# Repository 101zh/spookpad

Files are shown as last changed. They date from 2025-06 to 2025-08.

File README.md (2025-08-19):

# Spookpad

A 3x3 macropad made with the help of [Hack Club](https://hackclub.com/)'s [Hackpad](https://hackpad.hackclub.com) program.\
There are 8 keys that are backlit with LEDs, a rotary encoder, an OLED screen, and a XIAO RP2040 as the microcontroller.

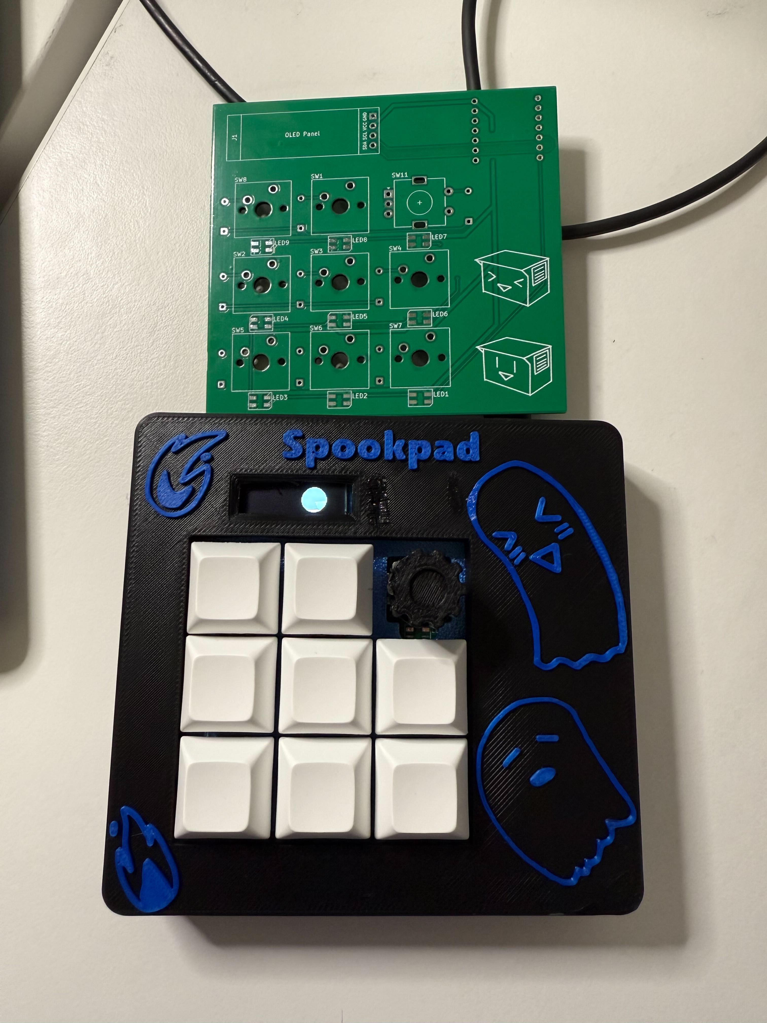
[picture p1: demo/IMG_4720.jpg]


https://github.com/user-attachments/assets/52a98100-4cb5-45ce-95d2-a7054d29ba24

## CAD

The case fits together using four M3 bolts and four M3 heatset inserts.\
The case is made of three separate printed pieces.\
The PCB just floats inside the 3D printed case. I would suggest that some insulation or some other material is placed inside, so that the PCB can be properly supported, instead of being supported by the sautered joints.

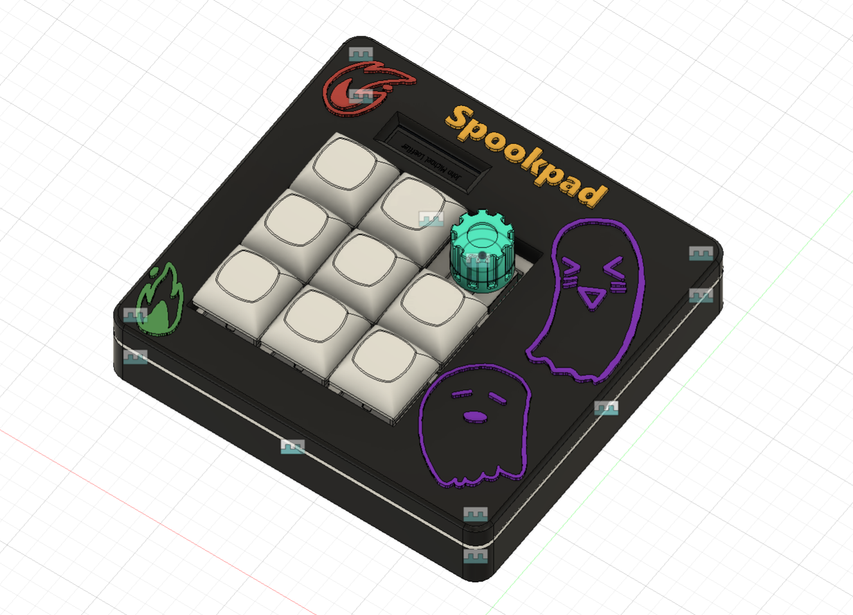
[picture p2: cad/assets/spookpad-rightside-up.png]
An image of the spookpad rightside up

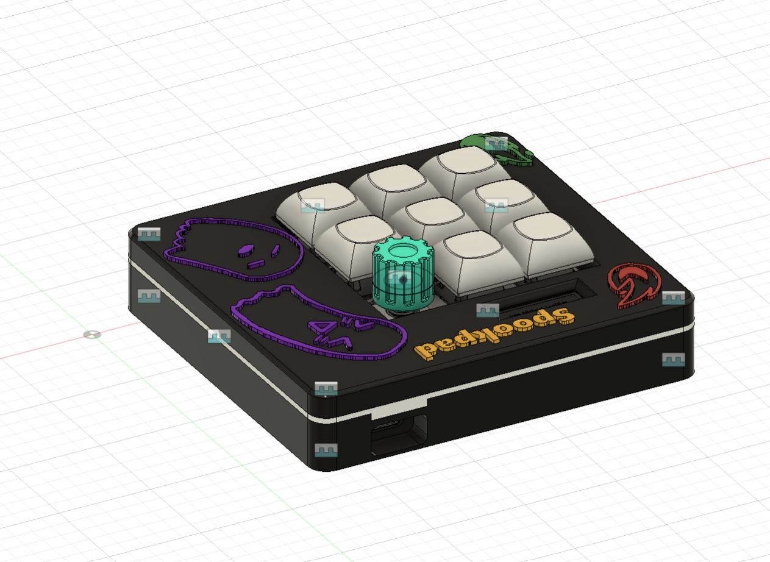
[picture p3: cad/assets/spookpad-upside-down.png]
An image of the spookpad upside down


## PCB

The PCB was created in KiCad. The silkscreen images were imported using KiCad's image converter.

### Schematic

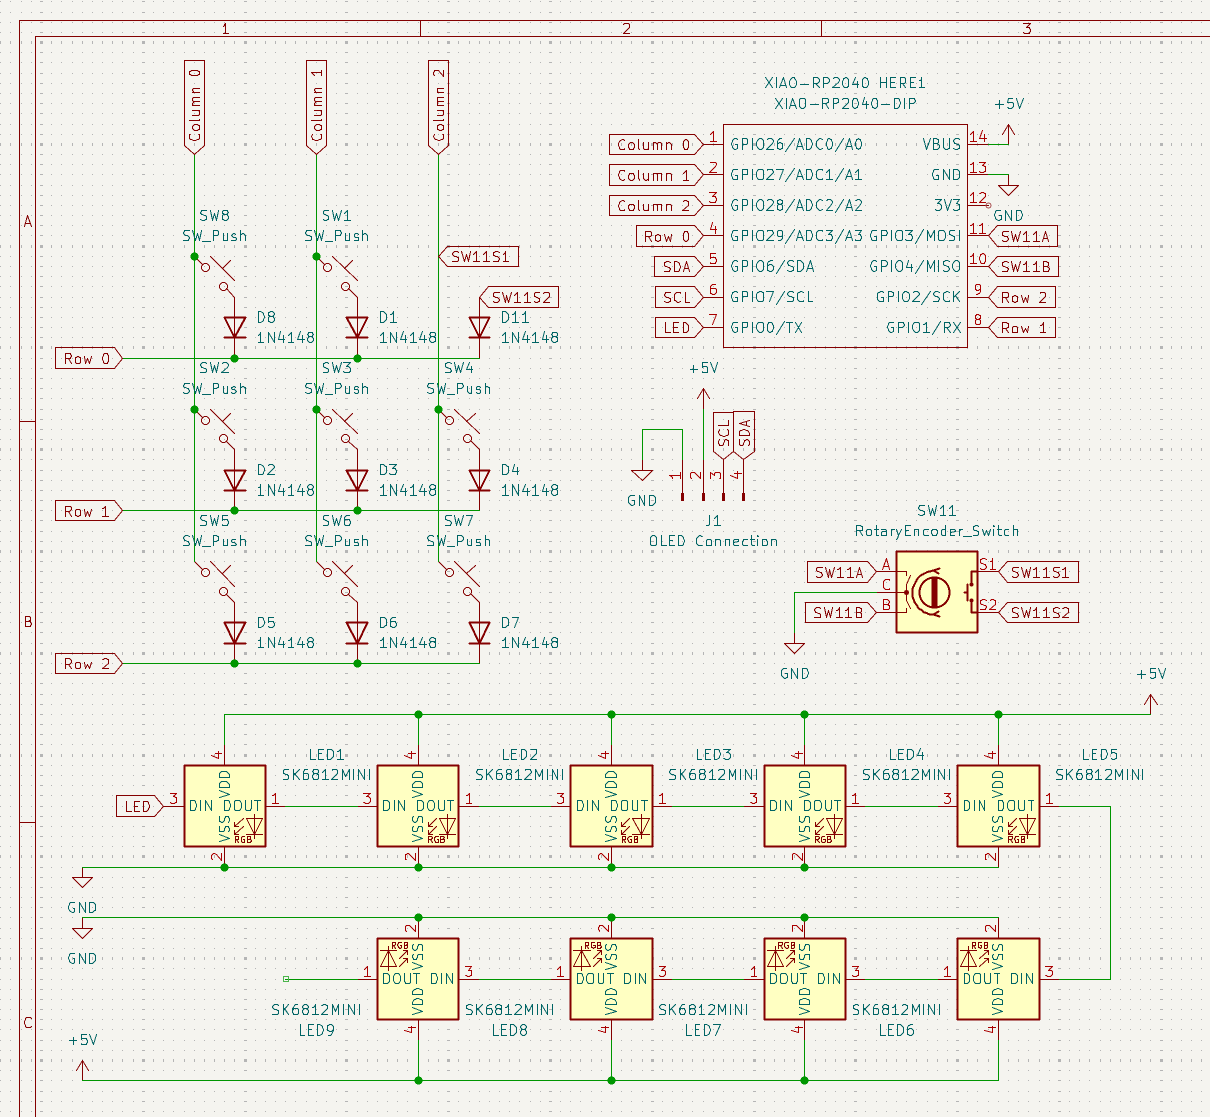
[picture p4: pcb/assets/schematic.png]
An image of the schematic, containing a wired key matrix, a micro controller, LEDs, and a rotary encoder


#### PCB With Zones

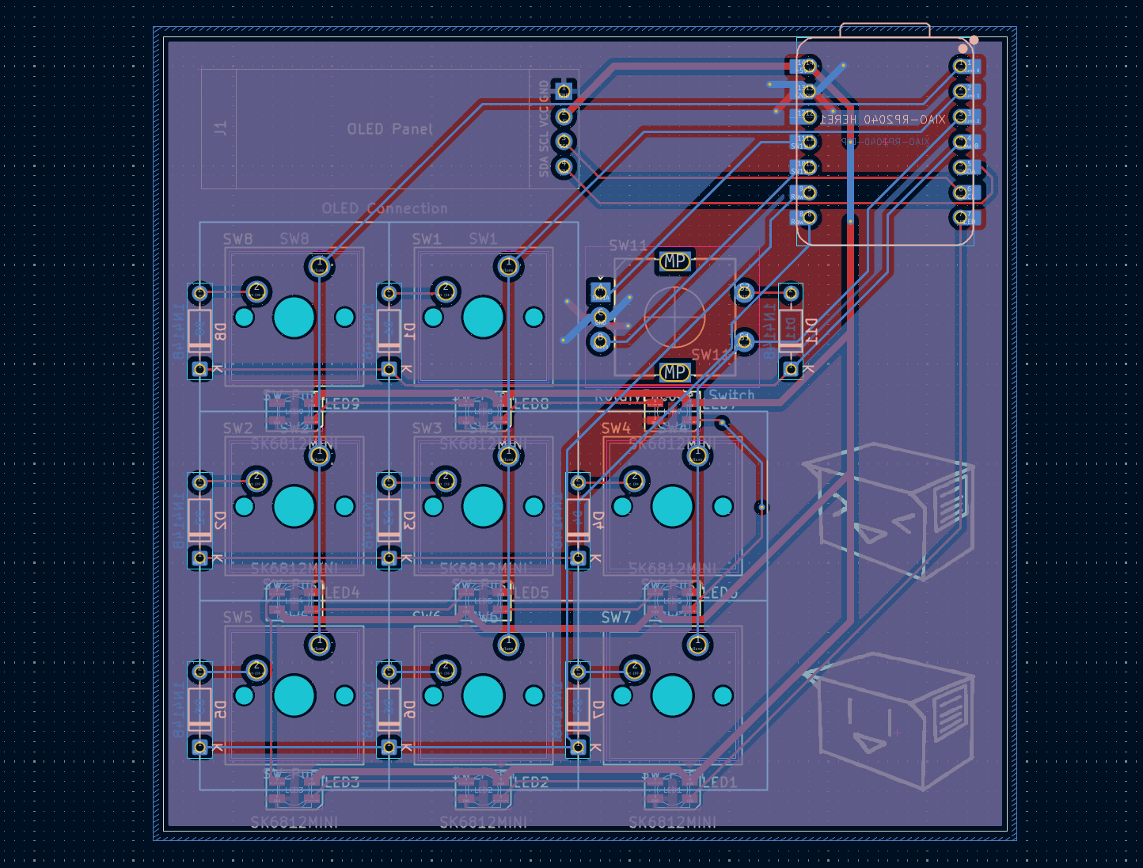
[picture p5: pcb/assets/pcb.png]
An image of the PCB with zones toggled as visible


#### PCB Without Zones

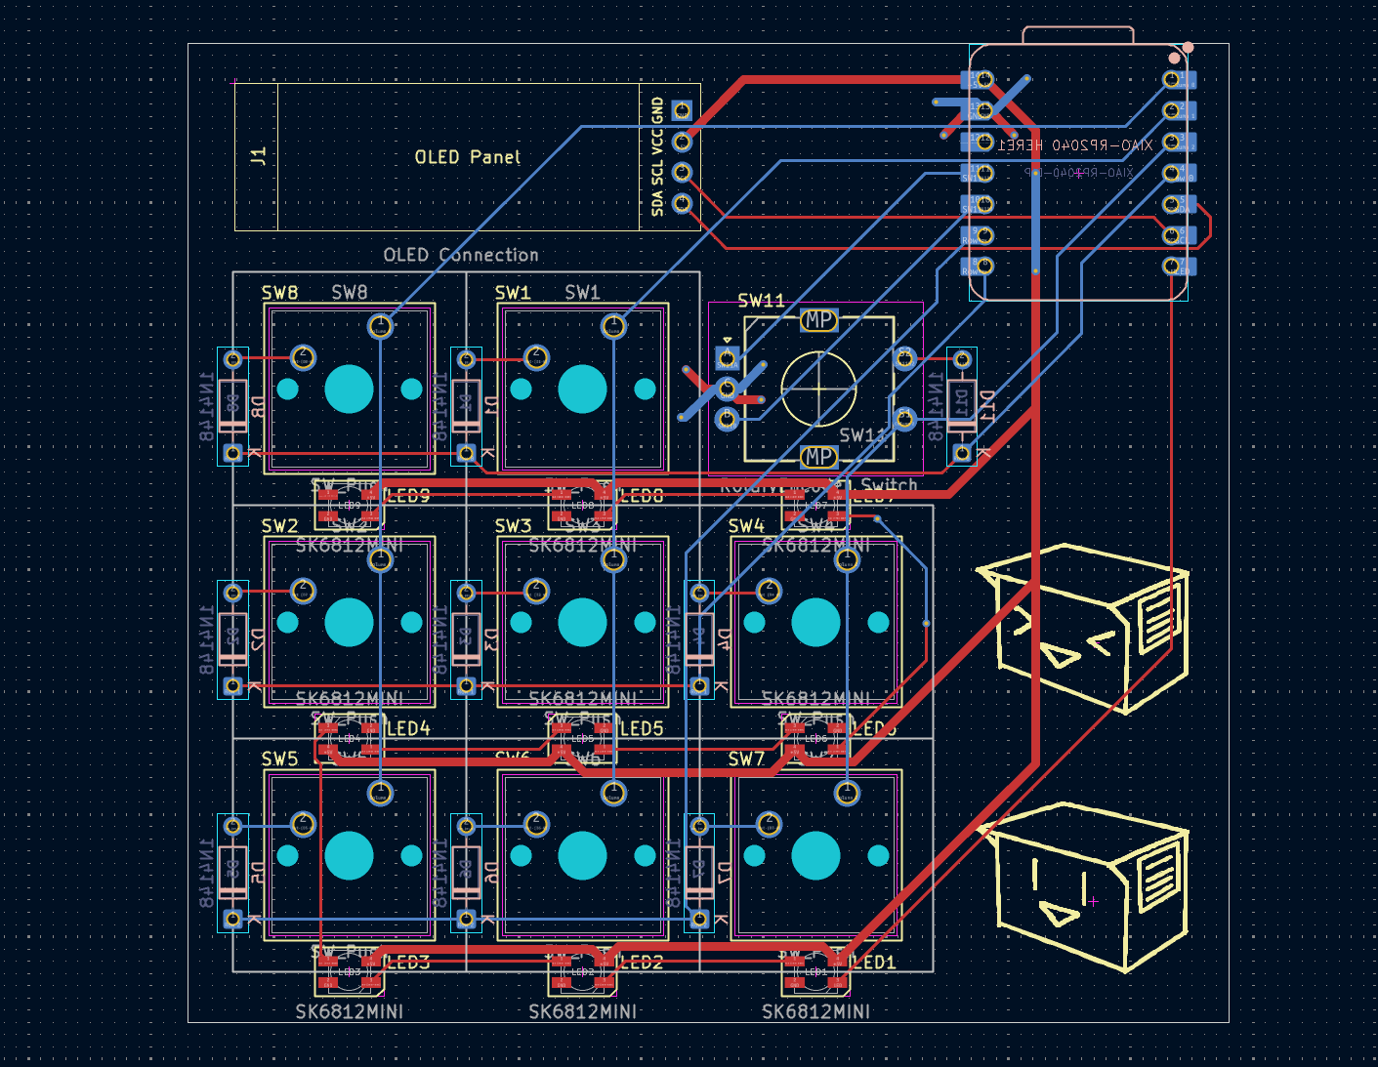
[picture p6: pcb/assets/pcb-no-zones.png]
An image of the PCB with zones toggled as not visible


## Firmware

This macropad uses [QMK](https://docs.qmk.fm/) for firmware.

- Rotary encoder knob adjusts the volume.
- By default, each key is bound to type out a number. The keys can type out the numbers 1 through 9. (There aren't enough keys to type out the number 0)
- This macropad is compatible with [VIA](https://caniusevia.com/), so that it can actually macro.
- The OLED screen should play the animation below at all times\
a .gif file of the animation, which shows a ball that flies back and forth
  - Still playing with the idea of displaying useful information.

## Bill of Materials (BOM)

Physical materials needed to make this macropad:

- 8x Cherry MX Switches
- 8x DSA Keycaps
- 1x EC11 Rotary Encoder
- 9x Through-hole 1N4148 Diodes
- 9x SK6812 MINI LEDs
- 4x M3x16mm Screws
- 4x M3x5mx4mm Heatset Inserts
- 1x 0.91" OLED Display
- 1x Seeed Studio XIAO RP2040
- 1x 3D printed knob for the rotary encoder
- 1x 3D printed case (3 separate pieces)

## Copyright

Copyright (C) 2025 101zh

This Source Code Form is subject to the terms of the Mozilla Public License, v. 2.0. If a copy of the MPL was not distributed with this file, You can obtain one at <https://mozilla.org/MPL/2.0/>.

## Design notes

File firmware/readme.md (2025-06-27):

# 101zh/spookinator

101zh/spookinator

*A short description of the keyboard/project*

* Keyboard Maintainer: [101zh](https://github.com/101zh)
* Hardware Supported: *The PCBs, controllers supported*
* Hardware Availability: *Links to where you can find this hardware*

Make example for this keyboard (after setting up your build environment):

    make 101zh/spookinator:default

Flashing example for this keyboard:

    make 101zh/spookinator:default:flash

See the [build environment setup](https://docs.qmk.fm/#/getting_started_build_tools) and the [make instructions](https://docs.qmk.fm/#/getting_started_make_guide) for more information. Brand new to QMK? Start with our [Complete Newbs Guide](https://docs.qmk.fm/#/newbs).

## Bootloader

Enter the bootloader in 3 ways:

* **Bootmagic reset**: Hold down the key at (0,0) in the matrix (usually the top left key or Escape) and plug in the keyboard
* **Physical reset button**: Briefly press the button on the back of the PCB - some may have pads you must short instead
* **Keycode in layout**: Press the key mapped to `QK_BOOT` if it is available

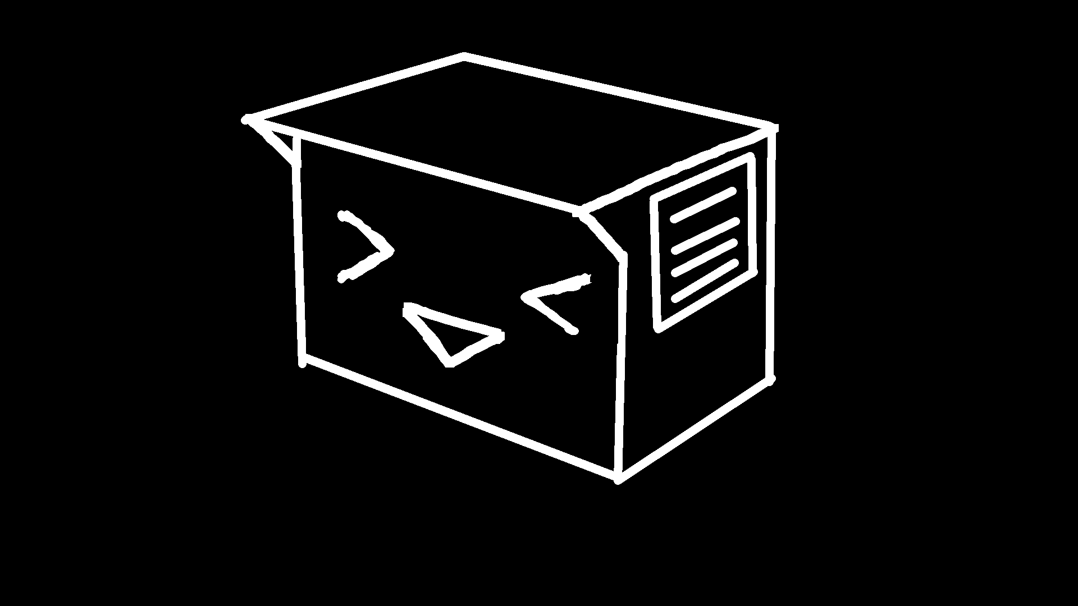
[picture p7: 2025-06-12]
pcb/assets/silkscreen/tv2.png

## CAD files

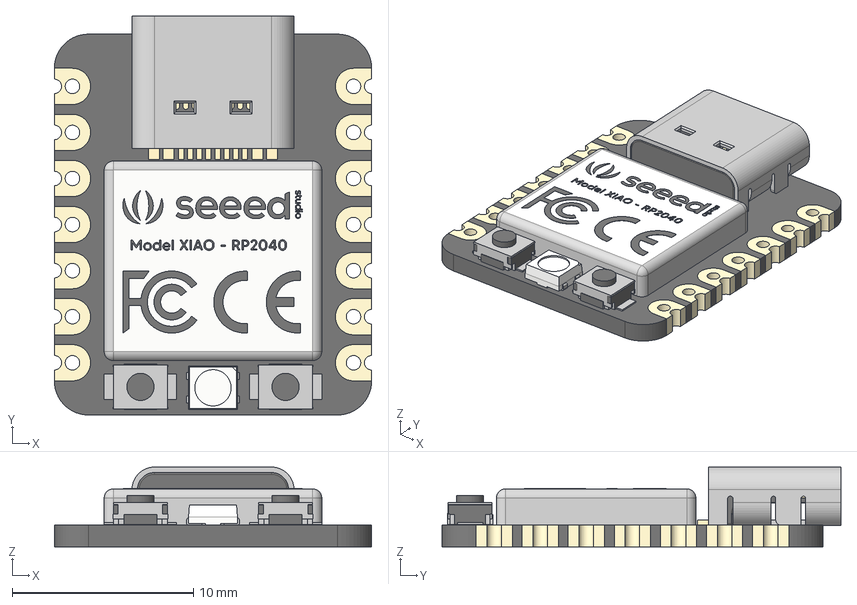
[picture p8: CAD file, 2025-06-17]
pcb/assets/3D_Models/Seeed Studio XIAO RP2040 v26.step
17.5 x 22.0 x 4.40 mm
Seeed Studio XIAO RP2040 v1 x 36
type-c v2 x 24
main x 16
smd_button v3
DIN
VDD
VSS
DOUT
smd_button v3(Mirror)

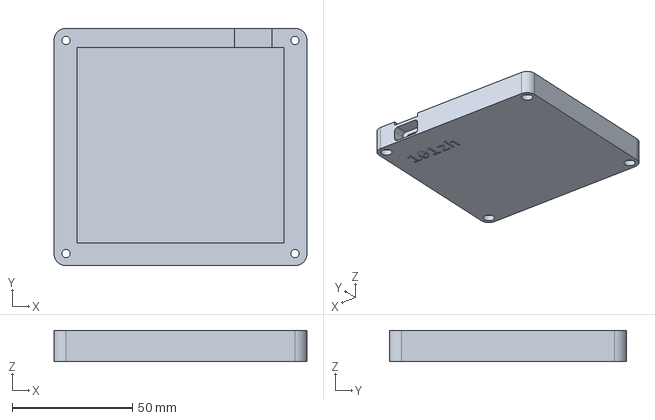
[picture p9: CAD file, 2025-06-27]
production/BottomCase.step
105.0 x 98.5 x 13.0 mm

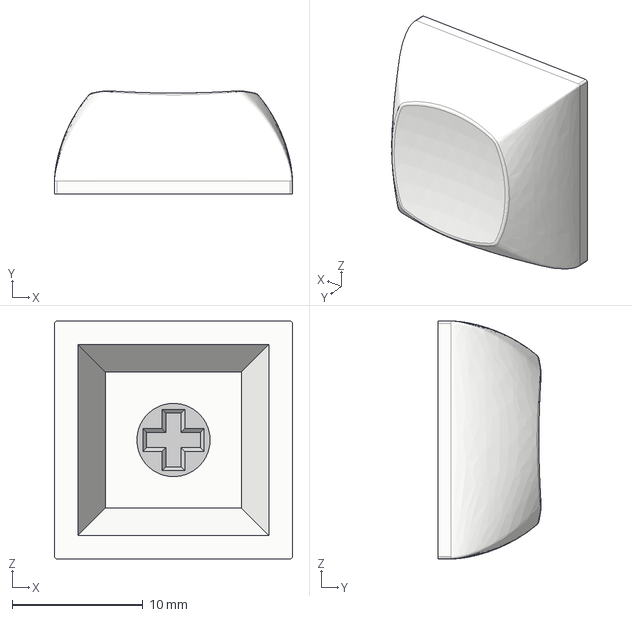
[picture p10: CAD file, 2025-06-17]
pcb/assets/3D_Models/DSA 1u v2.step
18.2 x 7.91 x 18.2 mm
DSA 1u v2
MX Mount v1

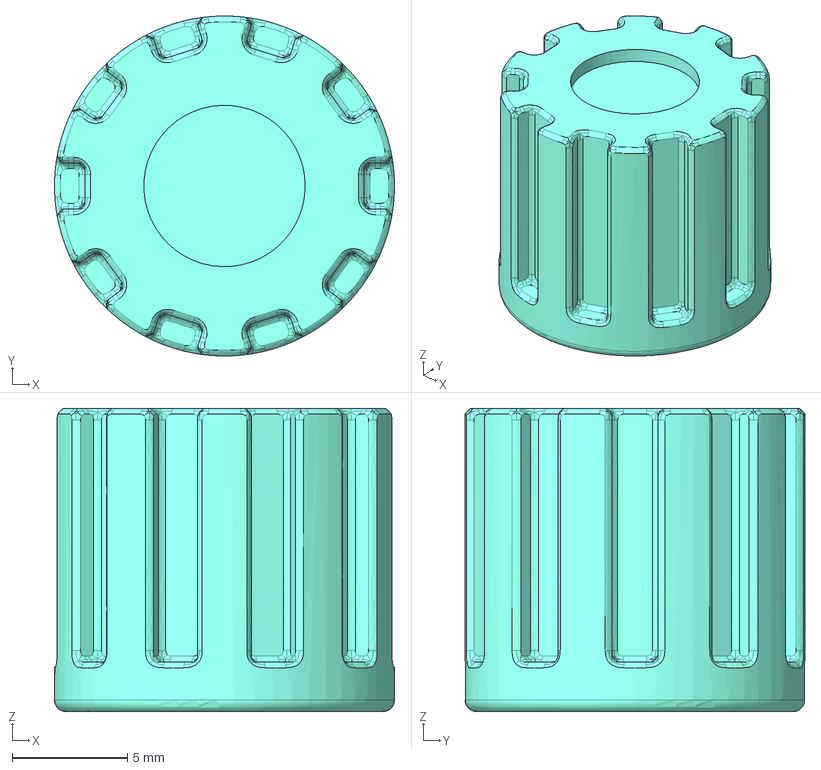
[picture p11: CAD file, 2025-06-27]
production/Knob.step
14.8 x 14.7 x 13.2 mm

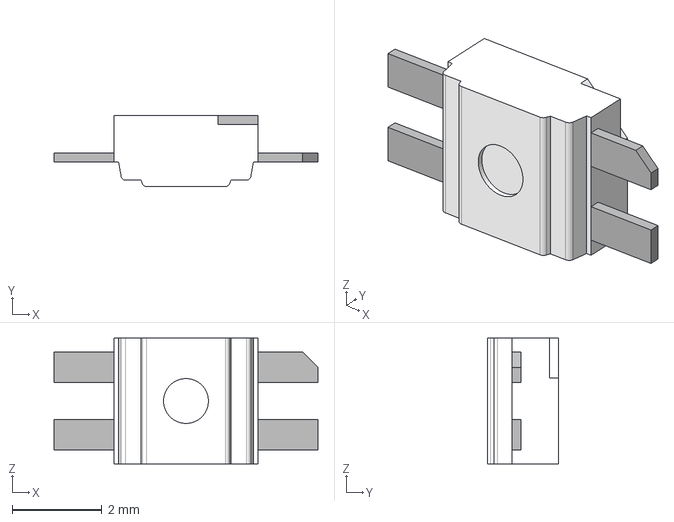
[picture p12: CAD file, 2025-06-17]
pcb/assets/3D_Models/SK6812MINI-E v1.step
5.88 x 1.58 x 2.80 mm

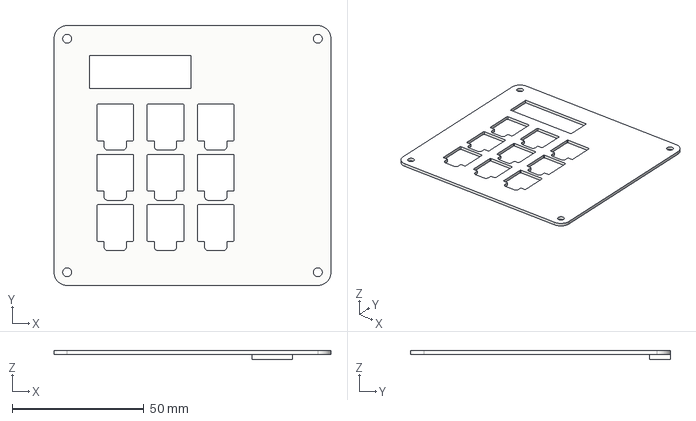
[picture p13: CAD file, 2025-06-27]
production/MiddleCase.step
105.0 x 98.5 x 3.45 mm

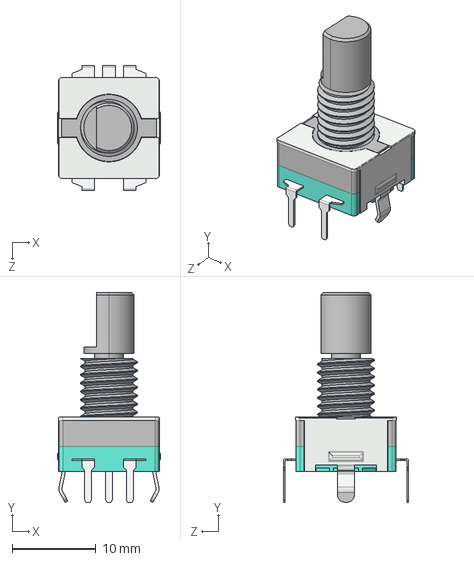
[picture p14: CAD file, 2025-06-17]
pcb/assets/3D_Models/EC11RotaryEncoder.STEP
12.3 x 25.1 x 15.0 mm

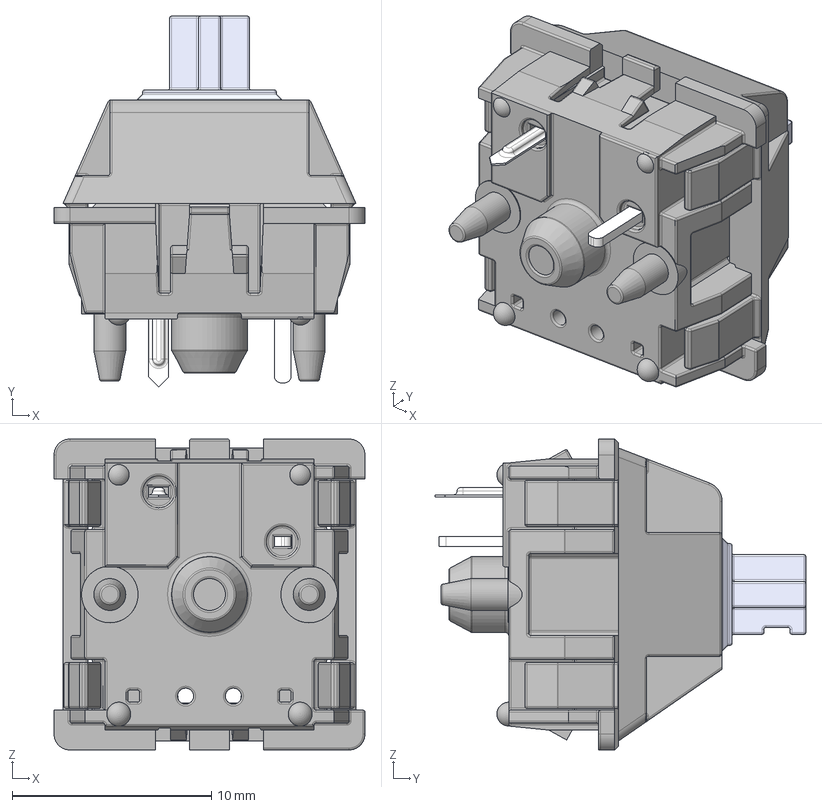
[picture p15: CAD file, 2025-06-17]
pcb/assets/3D_Models/Cherry MX Switch Base v2.step
15.6 x 18.6 x 15.6 mm
���___Ĭ��__��_ x 2
MX�� ���� �ײ� �̡�2 __Ĭ��_��2____��_
MX �� ������_��_ __��1
MX �� ���娢��_���顧_ _

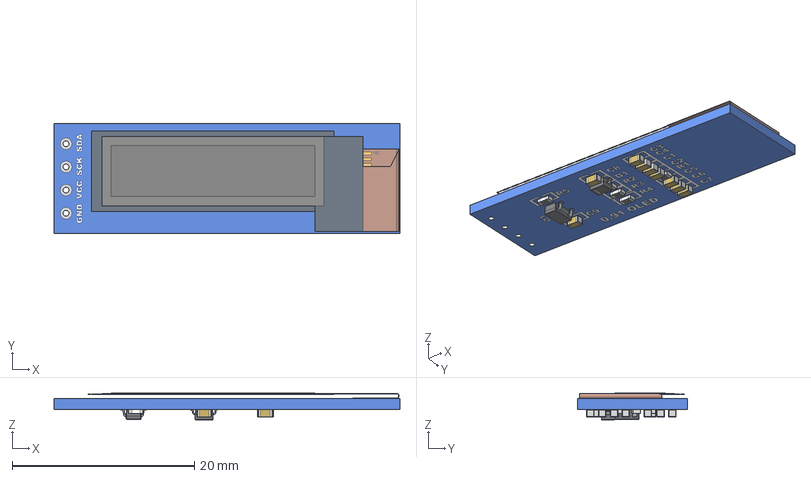
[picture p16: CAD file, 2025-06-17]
pcb/assets/3D_Models/0.91in OLED Module - Without Glass v1.step
37.9 x 12.1 x 2.93 mm
0603 Capacitor x 9
SOT23-3
Diode (SOD-323)
0.91in OLED - Folded Flush - Without Glass x 2
0603 Resistor x 5
0.91in oled Module - Board

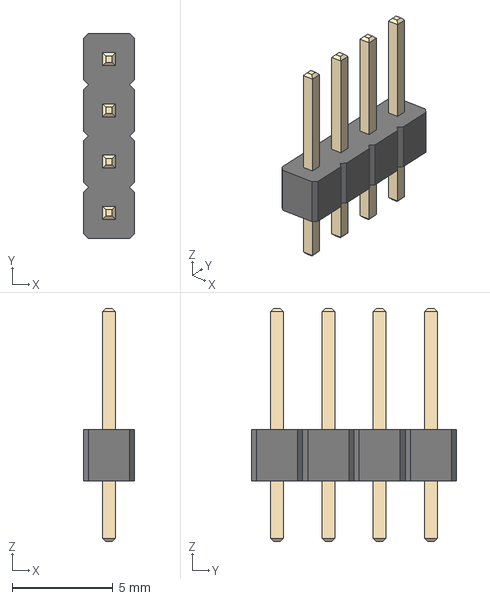
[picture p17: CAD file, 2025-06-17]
pcb/assets/3D_Models/PinHeader_1x04_P2.54mm_Vertical.step
2.54 x 10.2 x 11.5 mm

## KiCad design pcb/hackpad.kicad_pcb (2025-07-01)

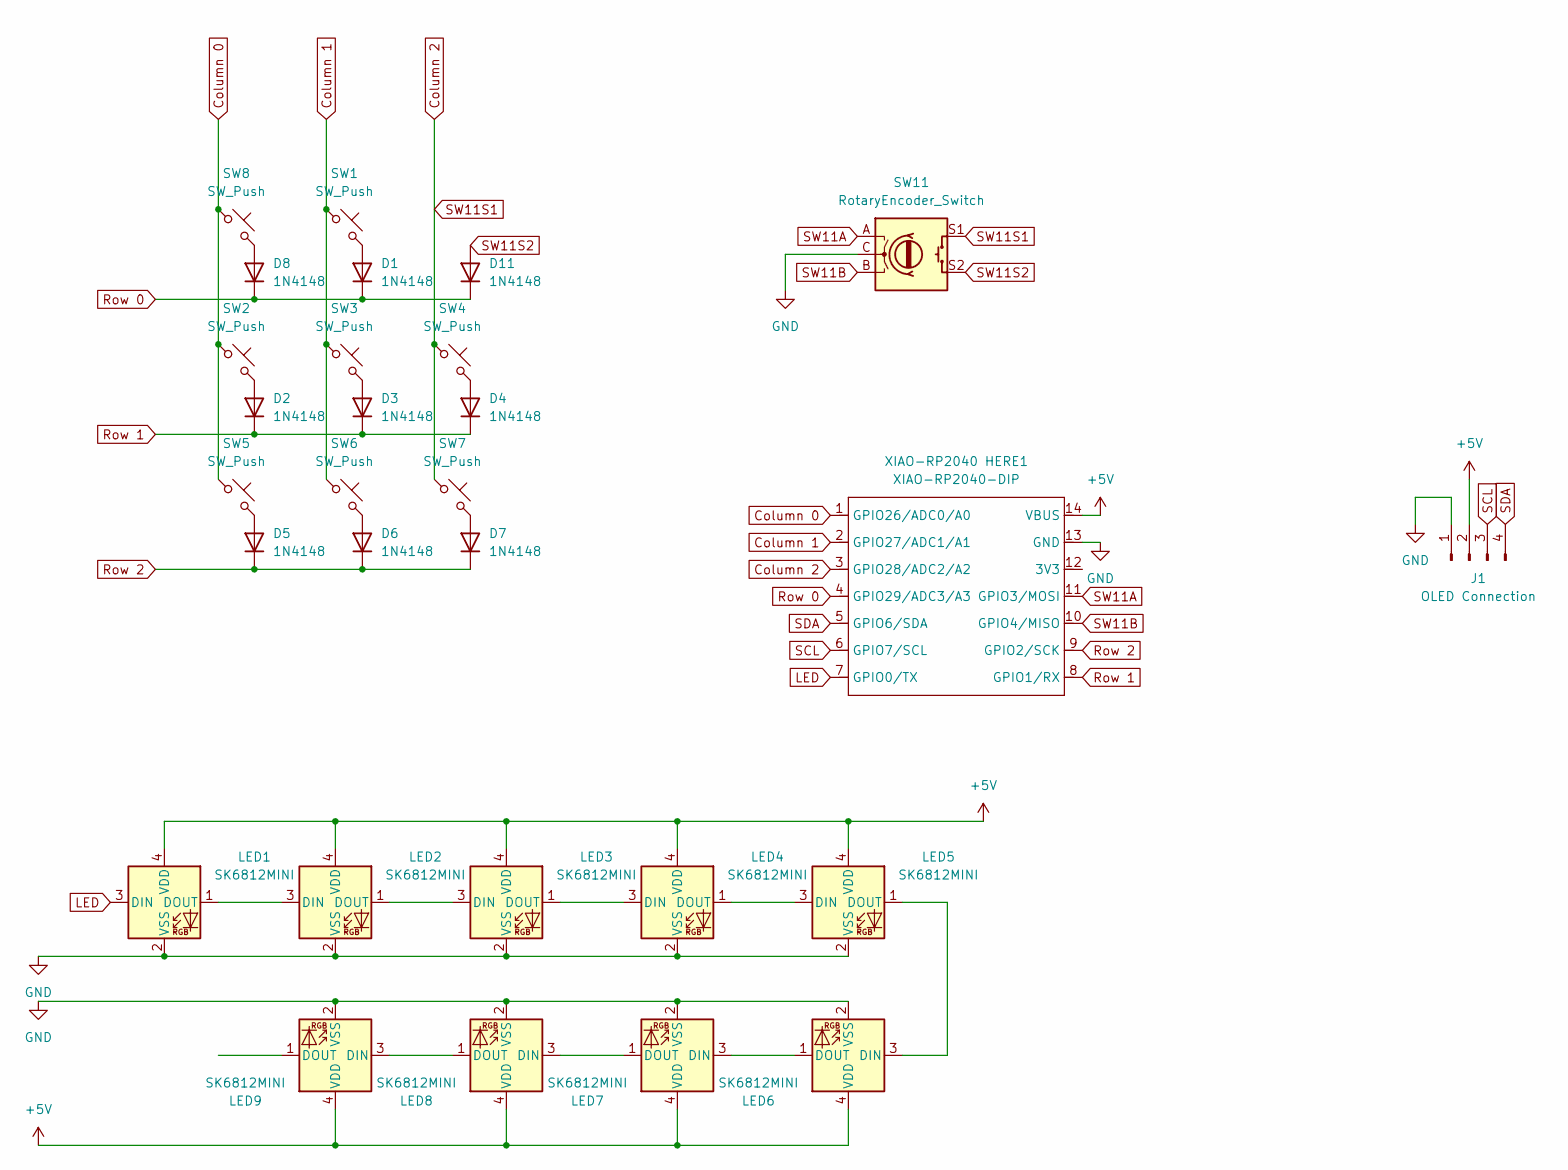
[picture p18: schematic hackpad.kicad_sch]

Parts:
D1, D2, D3, D4, D5, D6, D7, D8, D11: 1N4148; D_DO-35_SOD27_P7.62mm_Horizontal
J1: OLED Connection; 0.91-OLED-4pin
LED1, LED2, LED3, LED4, LED5, LED6, LED7, LED8, LED9: SK6812MINI; LED_SK6812MINI
SW1, SW2, SW3, SW4, SW5, SW6, SW7, SW8: SW_Push; SW_Cherry_MX_1.00ul
SW11: RotaryEncoder_Switch; RotaryEncoder_Alps_EC11E-Switch
XIAO-RP2040 HERE1: XIAO-RP2040-DIP; XIAO-RP2040-DIP_3D_Model

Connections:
+5V: J1.2, LED1.4 (VDD), LED2.4 (VDD), LED3.4 (VDD), LED4.4 (VDD), LED5.4 (VDD), LED6.4 (VDD), LED7.4 (VDD), LED8.4 (VDD), LED9.4 (VDD), XIAO-RP2040 HERE1.14 (VBUS)
Column 0: SW2.1, SW5.1, SW8.1, XIAO-RP2040 HERE1.1 (GPIO26/ADC0/A0)
Column 1: SW1.1, SW3.1, SW6.1, XIAO-RP2040 HERE1.2 (GPIO27/ADC1/A1)
Column 2: SW4.1, SW7.1, SW11.S1, XIAO-RP2040 HERE1.3 (GPIO28/ADC2/A2)
GND: J1.1, LED1.2 (VSS), LED2.2 (VSS), LED3.2 (VSS), LED4.2 (VSS), LED5.2 (VSS), LED6.2 (VSS), LED7.2 (VSS), LED8.2 (VSS), LED9.2 (VSS), SW11.C, XIAO-RP2040 HERE1.13 (GND)
LED: LED1.3 (DIN), XIAO-RP2040 HERE1.7 (GPIO0/TX)
unnamed: D1.2 (A), SW1.2
unnamed: D2.2 (A), SW2.2
unnamed: D3.2 (A), SW3.2
unnamed: D4.2 (A), SW4.2
unnamed: D5.2 (A), SW5.2
unnamed: D6.2 (A), SW6.2
unnamed: D7.2 (A), SW7.2
unnamed: D8.2 (A), SW8.2
unnamed: LED1.1 (DOUT), LED2.3 (DIN)
unnamed: LED2.1 (DOUT), LED3.3 (DIN)
unnamed: LED3.1 (DOUT), LED4.3 (DIN)
unnamed: LED4.1 (DOUT), LED5.3 (DIN)
unnamed: LED5.1 (DOUT), LED6.3 (DIN)
unnamed: LED6.1 (DOUT), LED7.3 (DIN)
unnamed: LED7.1 (DOUT), LED8.3 (DIN)
unnamed: LED8.1 (DOUT), LED9.3 (DIN)
Row 0: D1.1 (K), D8.1 (K), D11.1 (K), XIAO-RP2040 HERE1.4 (GPIO29/ADC3/A3)
Row 1: D2.1 (K), D3.1 (K), D4.1 (K), XIAO-RP2040 HERE1.8 (GPIO1/RX)
Row 2: D5.1 (K), D6.1 (K), D7.1 (K), XIAO-RP2040 HERE1.9 (GPIO2/SCK)
SCL: J1.3, XIAO-RP2040 HERE1.6 (GPIO7/SCL)
SDA: J1.4, XIAO-RP2040 HERE1.5 (GPIO6/SDA)
SW11A: SW11.A, XIAO-RP2040 HERE1.11 (GPIO3/MOSI)
SW11B: SW11.B, XIAO-RP2040 HERE1.10 (GPIO4/MISO)
SW11S2: D11.2 (A), SW11.S2

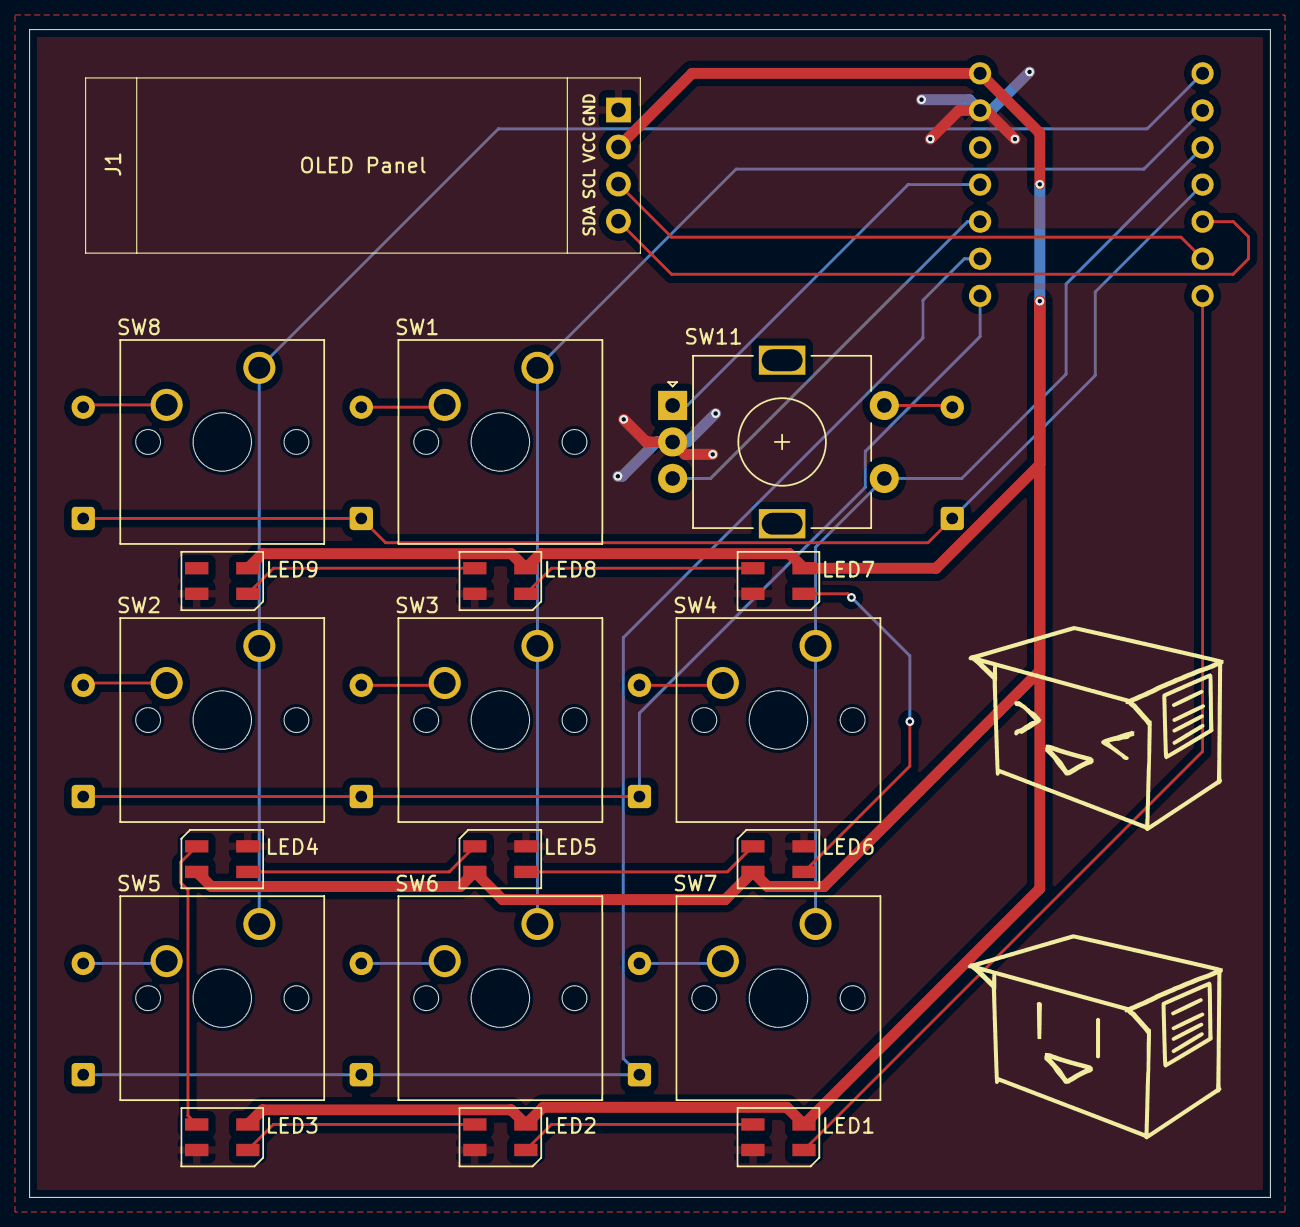
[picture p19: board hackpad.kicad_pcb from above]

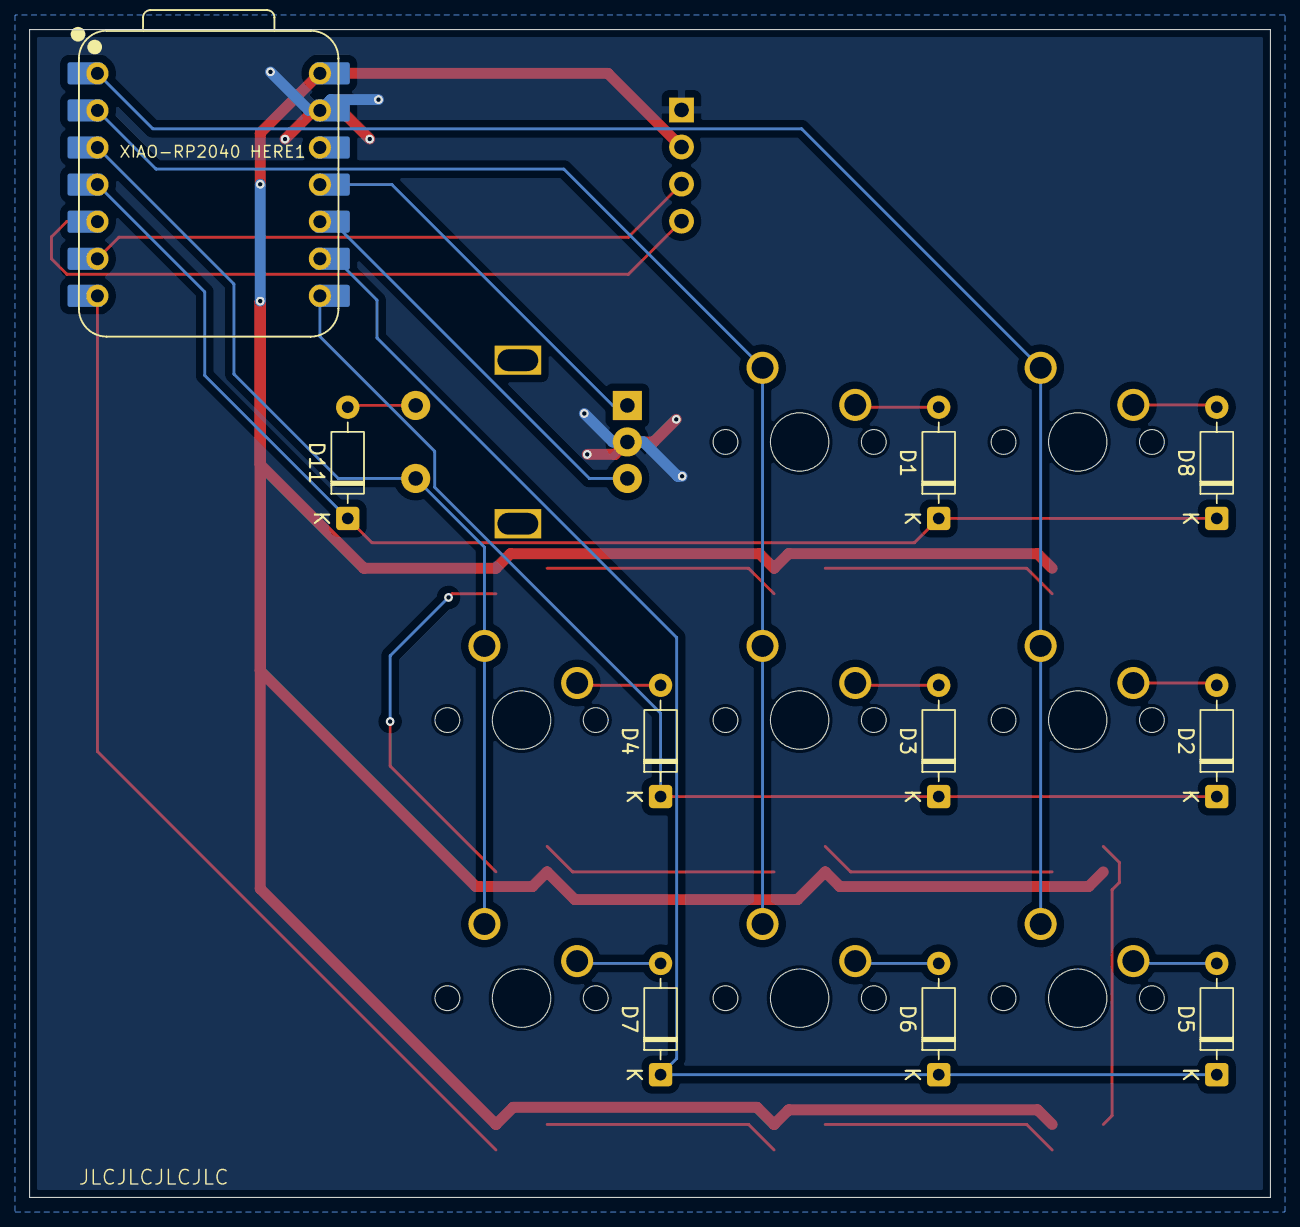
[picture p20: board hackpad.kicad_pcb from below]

Board: 2 copper layers, 85.0 x 80.0 mm, 29 parts (10 on the bottom side), 30 nets.

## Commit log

2025-05-21 create project
    [Grove - Vision AI Module V2.kicad_pcb, Grove - Vision AI Module V2.kicad_sch, Grove_Vision_AI_V2_BOM.xlsx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]
2025-05-24 brainstorm ideas for macropad
    - Why did this take so long...? (┬┬﹏┬┬)
2025-05-29 add wanted components in schematic
    [hackpad.kicad_pcb, hackpad.kicad_sch]
2025-05-31 finish schematic
    [hackpad.kicad_sch]
2025-06-02 place keys and OLED screen in place
    [hackpad.kicad_pcb, hackpad.kicad_sch]
2025-06-02 finalize key and OLED screen placement
    [hackpad.kicad_pcb, hackpad.kicad_sch]
2025-06-03 route some pcb components
    [hackpad.kicad_pcb]
2025-06-03 redesign macropad
    - I just realized that I forgot the row pins 〒▽〒
    [hackpad.kicad_sch]
2025-06-12 finish pcb
    [hackpad.kicad_pcb, hackpad.kicad_sch]
2025-06-17 add 3D models for footprints
    [0.91in OLED Module - Without Glass v1.step, Cherry MX Switch Base v2.step, DSA 1u v2.step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]
2025-06-17 adjust edge cuts and 3D models
    [Seeed Studio XIAO RP2040 v26.step, hackpad.kicad_pcb]
2025-06-18 make changes according to advice
    [hackpad.kicad_pcb]
2025-06-24 add images that are on the case
2025-06-24 update 3D model of pcb with small adjustments
    [DSA 1u v2.step, hackpad.kicad_pcb]
2025-06-27 reorganize for hackpad submission
    [0.91in OLED Module - Without Glass v1.step, Cherry MX Switch Base v2.step, DSA 1u v2.step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]
2025-06-27 add production files
    [BottomCase.step, Knob.step, MiddleCase.step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]
2025-06-30 edit pcb
    [hackpad.kicad_pcb]
2025-06-30 prepare pcb for ordering
2025-07-01 add drill files to gerbers.zip
    [hackpad.kicad_pcb]
2025-07-01 adjust top case
    - adjusted so that it can be 3D printed
    - also adjusted, so that images aren't too small
